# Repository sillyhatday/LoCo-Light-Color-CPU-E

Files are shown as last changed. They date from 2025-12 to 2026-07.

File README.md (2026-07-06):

# Introduction

As you may know, there are different revision CPUs that came in the GBC. All are compatible with each other except the last revision. This project allows for the use of that version inside of a Gameboy Light form factor.

The final revision CGB was cost cut as much as possible, Nintendo removed as much as they could from the console. All filtering removed by Nintendo has been removed from this also.

There is a bit of shell trimming required when assembling. The front face of the shell requires trimming for the screen like all IPS screen replacements. There is some trimming needed around the click wheel also as it's bigger than the orginal contrast wheel on a Light console. I'll document this when I have completed the build.

>[!IMPORTANT]
>This version only works with CGB-CPU-06 revisions, known as CPU-E

>[!NOTE]
>Limited new parts are needed, the 2.5v regulator and toggle wheel. I could have used the regulator from the donor, it just has an odd pin out. Such a small part is easy to loose or damage, so I went with a new part with a standard pin out. Everything else is the same as the original version.

Here is Natalie's origiinal readme with my images.

# LoCo (Light Color) - NatalieTheNerd

LoCo-CPU-E-Front

LoCo-CPU-E-Femboys







LoCo = Light Color. This project allows you to put a Game Boy Color in a Game Boy Light shell. Full Light colour PCB using the original parts. This board is made with modern screen kits in mind meaning it does not have the voltage rails for the original screen.

**ORDER AT 1MM WITH ENIG**

You can support me on Ko-Fi or by buying the board directly from me [my store](https://nataliethenerd.com/collections/all)

I also occasionally sell pre built PCBs on my store.



## Building

LoCo-PCB-Front-Back

> [!WARNING]
> I am not responsible for your skill issues!

>[!TIP]
>Some details that will need your atention during assembly are [here](SHELLTRIMMING.md)

This board uses all the parts of an original Game Boy Color minus the IR and original screen circuit. Most parts are in the same spot, however if you are having trouble you can check the [interactive BOM](https://nataliethenerd.github.io/loco.html)

The thumbwheel circuit can be connected to an OSD screen to control brightness. The two touch pad wires and be connected to the pads labelled ↑↓ on the back top left side of the board. The select, A and B pads are easy connection pads for the screen also. 

screenguide

**My recommendations** 

- New power regulator like my [Safer Charge DC](https://nataliethenerd.com/products/safer-charge-dc)
- [Q5 OSD Game Boy Color screen](https://s.click.aliexpress.com/e/_DmvDS95). The OSD allows you to move the screen

**New parts**

- [Thumbwheel](https://s.click.aliexpress.com/e/_DFcsKf1)

## Thanks
- Hozy for the pushing me to do the first ever Light Color
- Console and Casks for the thumbwheel circuit

## Follow me

If you are into Game Boy modding or retro gaming, please consider using code "NatalieTheNerd" at:

• [Retro Modding](http://RetroModding.com) 

• [Retro Game Repair Shop](http://RetroGameRepairShop.com) 

• [Extreme Rate](http://ExtremeRate.com)

**My socials**

• [Twitter](https://twitter.com/natalie_thenerd) 

• [BlueSky](https://bsky.app/profile/nataliethenerd.com) 

• [Instagram](https://www.instagram.com/natalie.thenerd/) 

• [Modded Gameboy Club](https://moddedgameboy.club/) - a club dedicated to the modification of Game Boys, freely sharing resources

## License

Please do not remove my logo, website and name.



The CC BY-SA 4.0 (Creative Commons Attribution-ShareAlike 4.0 International) license allows you to:

1. **Share** - Copy and redistribute the material in any medium or format.
2. **Adapt** - Remix, transform, and build upon the material for any purpose, even commercially.

### Conditions:

- **Attribution** - You must give appropriate credit, provide a link to the license, and indicate if changes were made. You may do so in any reasonable manner, but not in any way that suggests the licensor endorses you or your use.
- **ShareAlike** - If you remix, transform, or build upon the material, you must distribute your contributions under the same license as the original.

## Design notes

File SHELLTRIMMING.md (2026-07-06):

When it come time to assemble, there are a few points that require attention. Some of these I could fix in the PCB layout, but I cdon't see many poeple actually building this.

The contrast wheel is now replaced with the toggle wheel. This is larger than the original. The back shell requires the gap making larger.

LoCo-Contrast

The donor GBC crystal will likely be the wrong footprint. This was my temporary fix until getting a different crystal.

LoCo-CPU-Crystal

Here you can see there are some parts that will interfere with the back shell. It seem the last GBC rev comes with some fat fuses which are close to the back shell. One of the filters is also directly under the back shell, that is an issue in the original design. I could fix it, but it's an easy shell trim.

Some of these parts are removed in the newest model.

LoCo-Power-2

A clearer look without the shell. If using the Bucket Mouse voltage regulator, keep in mind where the extra wire is run. I could add a solder jumper for if the user wants to use that regulator. Maybe I will, but not right now.

LoCo-Power

Extra Optional Tips:

If using an alternative power regulator, I suggest removing the black part once the pins are all soldered. The height of the regulator from the main PCB pushes it into the front shell. I have not removed them and should do that.

regulatorSdeProfile

These pins collide with the front shell.

regulatorAngledView

I prefer the screen controls to be different from the assignments on the PCB. Swapping A and Select seems more intuitive to me.

buttonSolderPads

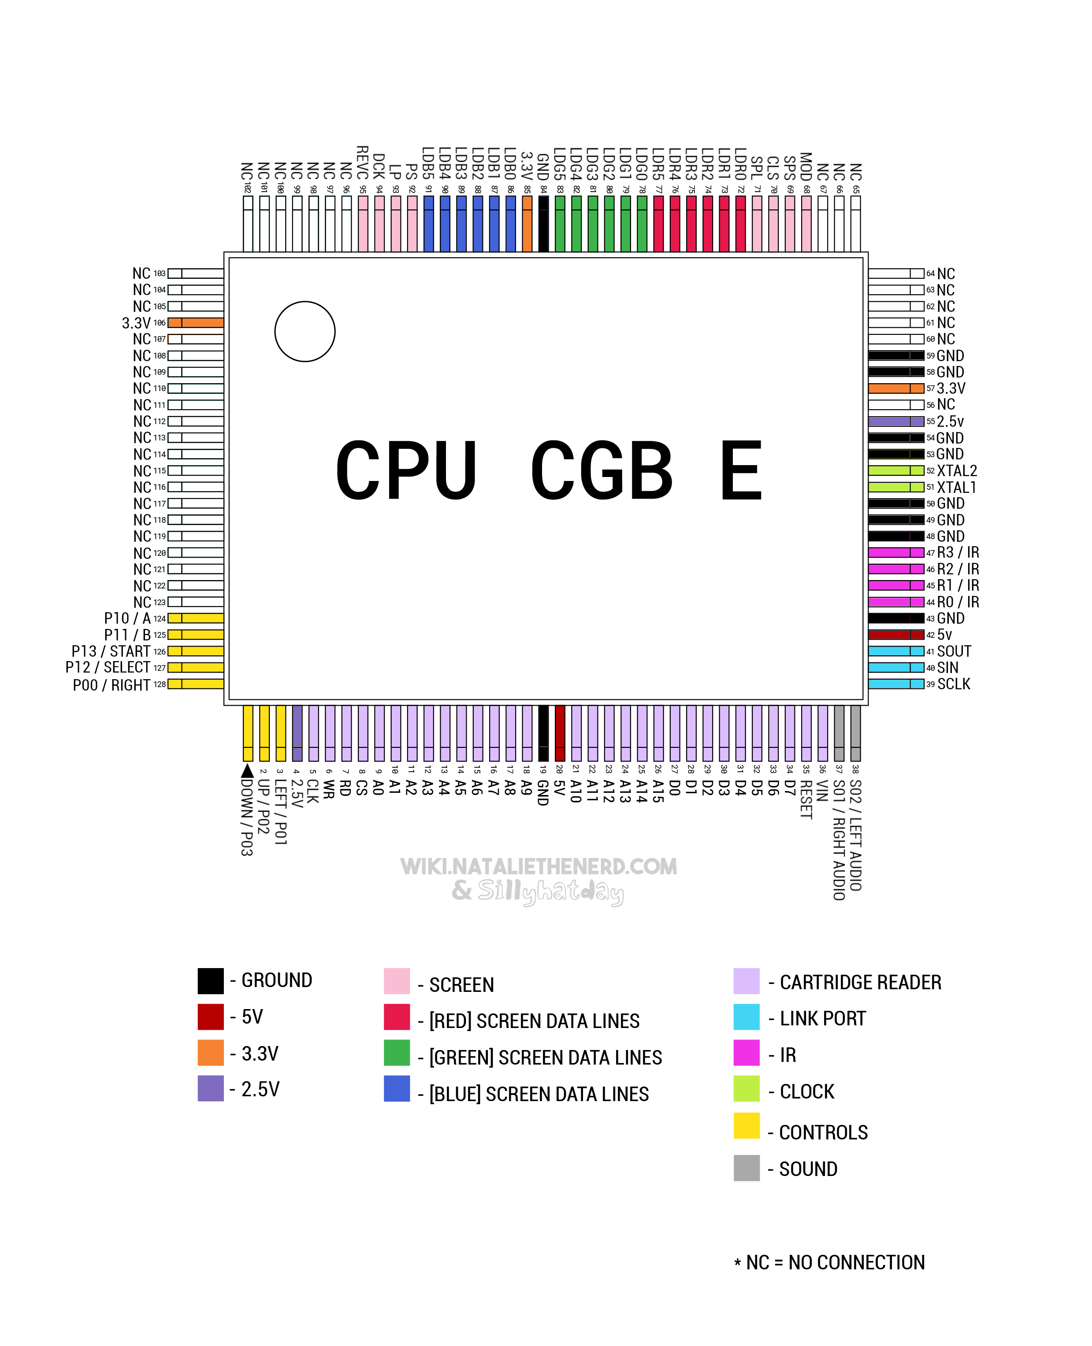
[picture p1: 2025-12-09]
GBC-CPU-E-PINOUT.png

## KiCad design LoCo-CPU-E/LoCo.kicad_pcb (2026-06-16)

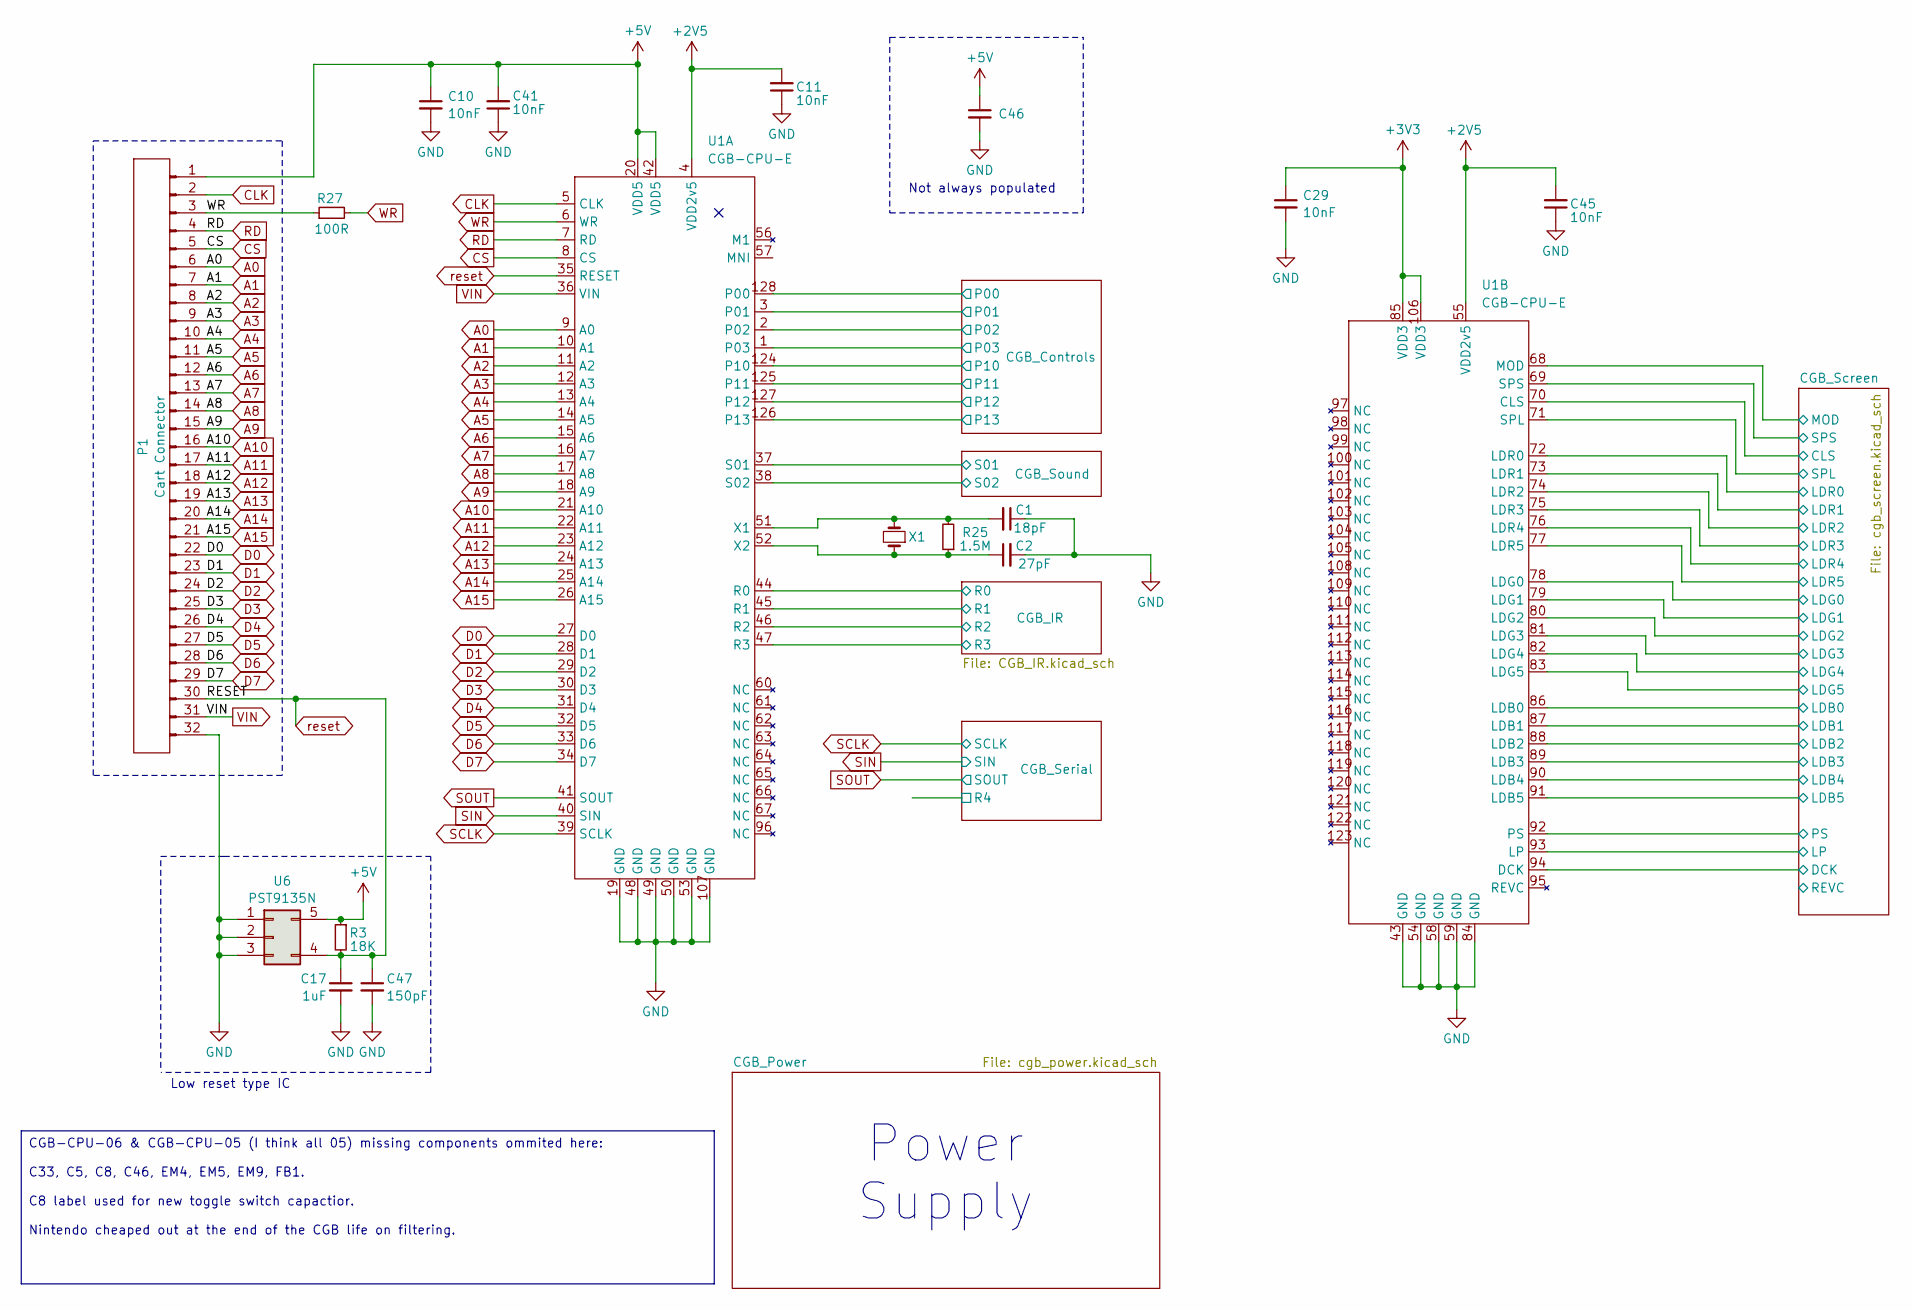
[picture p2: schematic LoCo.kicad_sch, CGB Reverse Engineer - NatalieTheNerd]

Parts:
C1: 18pF; C_0603_1608Metric
C2: 27pF; C_0603_1608Metric
C10, C11, C29, C41, C45: 10nF; C_0603_1608Metric
C17: 1uF; C_0603_1608Metric
C46: C_0603_1608Metric
C47: 150pF; C_0603_1608Metric
P1: Cart Connector; Cart CGB
R3: 18K; R_0603_1608Metric
R25: 1.5M; R_0603_1608Metric
R27: 100R; R_0603_1608Metric
U1: CGB-CPU-E; CPU CGB
U6: PST9135N; SOT-23-5
X1: Crystal_Small; Crystal CGB

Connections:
+2V5: C11.2, C45.2, U1.4 (VDD2v5), U1.55 (VDD2v5); also elsewhere on the board
+3V3: C29.1, U1.85 (VDD3), U1.106 (VDD3); also elsewhere on the board
+5V: C10.1, C41.2, C46.1, P1.1, R3.1, U1.20 (VDD5), U1.42 (VDD5), U6.5; also elsewhere on the board
/CGB_Controls/P00: U1.128 (P00); also elsewhere on the board
/CGB_Controls/P01: U1.3 (P01); also elsewhere on the board
/CGB_Controls/P02: U1.2; also elsewhere on the board
/CGB_Controls/P03: U1.1 (P03); also elsewhere on the board
/CGB_Controls/P10: U1.124 (P10); also elsewhere on the board
/CGB_Controls/P11: U1.125 (P11); also elsewhere on the board
/CGB_Controls/P12: U1.127 (P12); also elsewhere on the board
/CGB_Controls/P13: U1.126 (P13); also elsewhere on the board
/CGB_Screen/CLS: U1.70 (CLS); also elsewhere on the board
/CGB_Screen/DCK: U1.94 (DCK); also elsewhere on the board
/CGB_Screen/LDB0: U1.86 (LDB0); also elsewhere on the board
/CGB_Screen/LDB1: U1.87 (LDB1); also elsewhere on the board
/CGB_Screen/LDB2: U1.88 (LDB2); also elsewhere on the board
/CGB_Screen/LDB3: U1.89 (LDB3); also elsewhere on the board
/CGB_Screen/LDB4: U1.90 (LDB4); also elsewhere on the board
/CGB_Screen/LDB5: U1.91 (LDB5); also elsewhere on the board
/CGB_Screen/LDG0: U1.78 (LDG0); also elsewhere on the board
/CGB_Screen/LDG1: U1.79 (LDG1); also elsewhere on the board
/CGB_Screen/LDG2: U1.80 (LDG2); also elsewhere on the board
/CGB_Screen/LDG3: U1.81 (LDG3); also elsewhere on the board
/CGB_Screen/LDG4: U1.82 (LDG4); also elsewhere on the board
/CGB_Screen/LDG5: U1.83 (LDG5); also elsewhere on the board
/CGB_Screen/LDR0: U1.72 (LDR0); also elsewhere on the board
/CGB_Screen/LDR1: U1.73 (LDR1); also elsewhere on the board
/CGB_Screen/LDR2: U1.74 (LDR2); also elsewhere on the board
/CGB_Screen/LDR3: U1.75 (LDR3); also elsewhere on the board
/CGB_Screen/LDR4: U1.76 (LDR4); also elsewhere on the board
/CGB_Screen/LDR5: U1.77 (LDR5); also elsewhere on the board
/CGB_Screen/LP: U1.93 (LP); also elsewhere on the board
/CGB_Screen/MOD: U1.68 (MOD); also elsewhere on the board
/CGB_Screen/PS: U1.92 (PS); also elsewhere on the board
/CGB_Screen/SPL: U1.71 (SPL); also elsewhere on the board
/CGB_Screen/SPS: U1.69 (SPS); also elsewhere on the board
/CGB_Sound/S01: U1.37 (S01); also elsewhere on the board
/CGB_Sound/S02: U1.38 (S02); also elsewhere on the board
/R0: U1.44 (R0)
/R1: U1.45 (R1)
/R2: U1.46 (R2)
/R3: U1.47 (R3)
A0: P1.6, U1.9 (A0)
A1: P1.7, U1.10 (A1)
A2: P1.8, U1.11 (A2)
A3: P1.9, U1.12 (A3)
A4: P1.10, U1.13 (A4)
A5: P1.11, U1.14 (A5)
A6: P1.12, U1.15 (A6)
A7: P1.13, U1.16 (A7)
A8: P1.14, U1.17 (A8)
A9: P1.15, U1.18 (A9)
A10: P1.16, U1.21 (A10)
A11: P1.17, U1.22 (A11)
A12: P1.18, U1.23 (A12)
A13: P1.19, U1.24 (A13)
A14: P1.20, U1.25 (A14)
A15: P1.21, U1.26 (A15)
CLK: P1.2, U1.5 (CLK)
CS: P1.5, U1.8 (CS)
D0: P1.22, U1.27 (D0)
D1: P1.23, U1.28 (D1)
D2: P1.24, U1.29 (D2)
D3: P1.25, U1.30 (D3)
D4: P1.26, U1.31 (D4)
D5: P1.27, U1.32 (D5)
D6: P1.28, U1.33 (D6)
D7: P1.29, U1.34 (D7)
GND: C1.1, C2.2, C10.2, C11.1, C17.2, C29.2, C41.1, C45.1, C46.2, C47.2, P1.32, U1.19 (GND), U1.43 (GND), U1.48 (GND), U1.49 (GND), U1.50 (GND), U1.53 (GND), U1.54 (GND), U1.58 (GND), U1.59 (GND), U1.84 (GND), U1.107 (GND), U6.1, U6.2, U6.3; also elsewhere on the board
unnamed: C1.2, R25.2, U1.51 (X1), X1.2
unnamed: C2.1, R25.1, U1.52 (X2), X1.1
RD: P1.4, U1.7 (RD)
SCLK: U1.39 (SCLK); also elsewhere on the board
SIN: U1.40 (SIN); also elsewhere on the board
SOUT: U1.41 (SOUT); also elsewhere on the board
VIN: P1.31, U1.36 (VIN)
WR: P1.3, R27.1, R27.2, U1.6 (WR)
reset: C17.1, C47.1, P1.30, R3.2, U1.35 (RESET), U6.4; also elsewhere on the board

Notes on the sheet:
Not always populated
Power Supply
Low reset type IC
CGB-CPU-06 & CGB-CPU-05 (I think all 05) missing components ommited here: C33, C5, C8, C46, EM4, EM5, EM9, FB1. C8 label used for new toggle switch capactior. Nintendo cheaped out at the end of the CGB life on filtering.

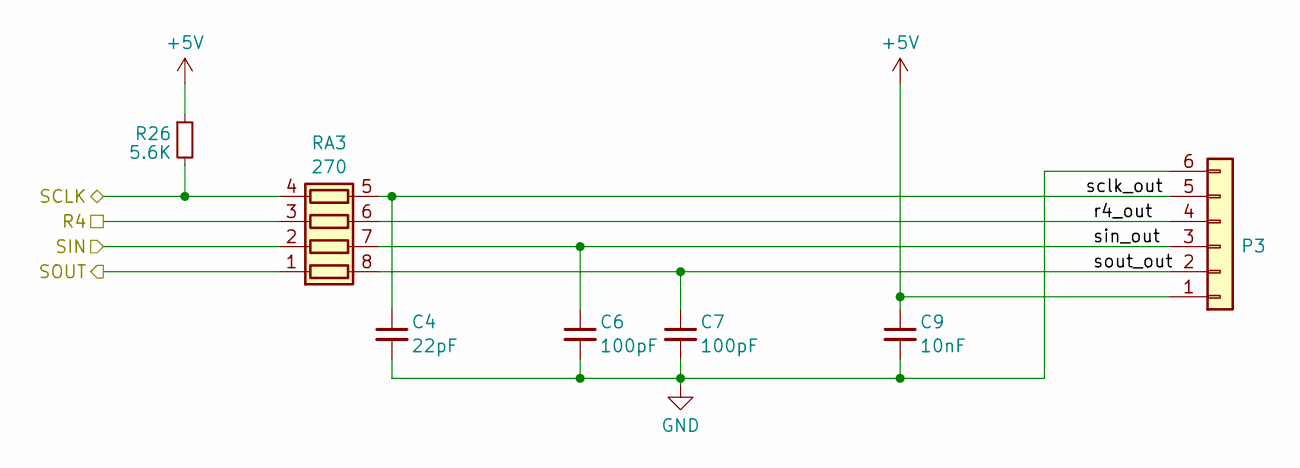
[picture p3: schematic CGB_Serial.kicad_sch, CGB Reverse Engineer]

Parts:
C4: 22pF; C_0603_1608Metric
C6, C7: 100pF; C_0603_1608Metric
C9: 10nF; C_0603_1608Metric
P3: Conn_01x06; Serial CGB
R26: 5.6K; R_0603_1608Metric
RA3: 270; R_Array_Concave_4x0603

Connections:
+5V: C9.1, P3.1, R26.1; also elsewhere on the board
/CGB_Serial/R4: RA3.3 (R3.1)
/CGB_Serial/r4_out: P3.4, RA3.6 (R3.2)
/CGB_Serial/sclk_out: C4.1, P3.5, RA3.5 (R4.2)
/CGB_Serial/sin_out: C6.1, P3.3, RA3.7 (R2.2)
/CGB_Serial/sout_out: C7.1, P3.2, RA3.8 (R1.2)
GND: C4.2, C6.2, C7.2, C9.2, P3.6; also elsewhere on the board
SCLK: R26.2, RA3.4 (R4.1); also elsewhere on the board
SIN: RA3.2 (R2.1); also elsewhere on the board
SOUT: RA3.1 (R1.1); also elsewhere on the board

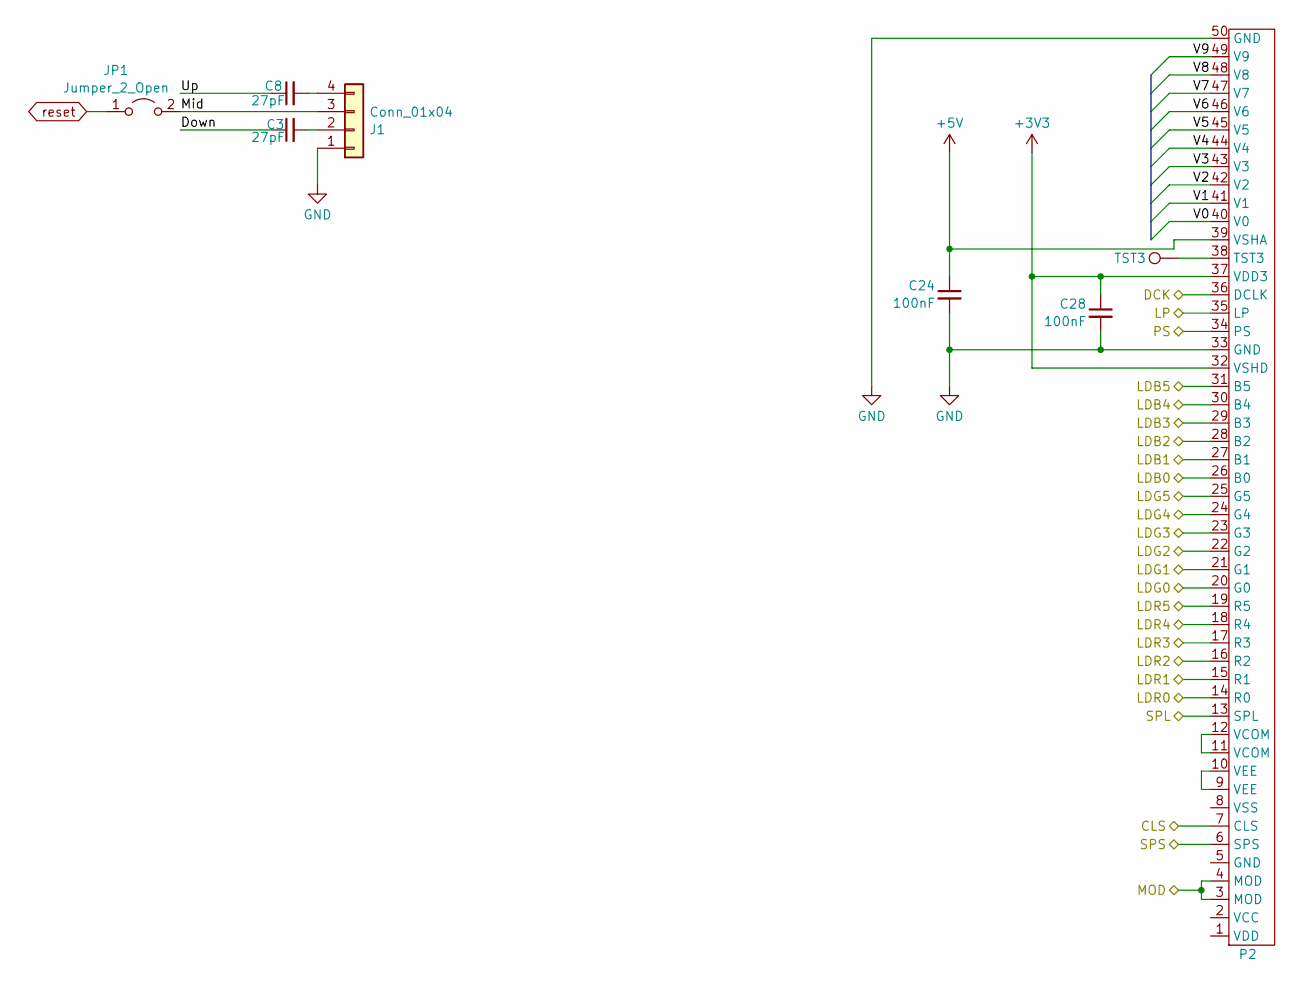
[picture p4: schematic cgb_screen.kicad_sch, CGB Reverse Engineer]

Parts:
C3, C8: 27pF; R_0603_1608Metric
C24, C28: 100nF; C_0603_1608Metric
J1: Conn_01x04; Thumbwheel toggle switch
JP1: Jumper_2_Open; SolderJumper-2_P1.3mm_Open_RoundedPad1.0x1.5mm
P2: Screen CGB
TST3: TestPoint

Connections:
+3V3: C28.1, P2.32 (VSHD), P2.37 (VDD3); also elsewhere on the board
+5V: C24.1, P2.39 (VSHA); also elsewhere on the board
/CGB_Screen/CLS: P2.7 (CLS); also elsewhere on the board
/CGB_Screen/DCK: P2.36 (DCLK); also elsewhere on the board
/CGB_Screen/Down: C3.1
/CGB_Screen/LDB0: P2.26 (B0); also elsewhere on the board
/CGB_Screen/LDB1: P2.27 (B1); also elsewhere on the board
/CGB_Screen/LDB2: P2.28 (B2); also elsewhere on the board
/CGB_Screen/LDB3: P2.29 (B3); also elsewhere on the board
/CGB_Screen/LDB4: P2.30 (B4); also elsewhere on the board
/CGB_Screen/LDB5: P2.31 (B5); also elsewhere on the board
/CGB_Screen/LDG0: P2.20 (G0); also elsewhere on the board
/CGB_Screen/LDG1: P2.21 (G1); also elsewhere on the board
/CGB_Screen/LDG2: P2.22 (G2); also elsewhere on the board
/CGB_Screen/LDG3: P2.23 (G3); also elsewhere on the board
/CGB_Screen/LDG4: P2.24 (G4); also elsewhere on the board
/CGB_Screen/LDG5: P2.25 (G5); also elsewhere on the board
/CGB_Screen/LDR0: P2.14 (R0); also elsewhere on the board
/CGB_Screen/LDR1: P2.15 (R1); also elsewhere on the board
/CGB_Screen/LDR2: P2.16 (R2); also elsewhere on the board
/CGB_Screen/LDR3: P2.17 (R3); also elsewhere on the board
/CGB_Screen/LDR4: P2.18 (R4); also elsewhere on the board
/CGB_Screen/LDR5: P2.19 (R5); also elsewhere on the board
/CGB_Screen/LP: P2.35 (LP); also elsewhere on the board
/CGB_Screen/MOD: P2.3 (MOD), P2.4 (MOD); also elsewhere on the board
/CGB_Screen/Mid: J1.3, JP1.2 (B)
/CGB_Screen/PS: P2.34 (PS); also elsewhere on the board
/CGB_Screen/SPL: P2.13 (SPL); also elsewhere on the board
/CGB_Screen/SPS: P2.6 (SPS); also elsewhere on the board
/CGB_Screen/Up: C8.1
/CGB_Screen/V0: P2.40 (V0)
/CGB_Screen/V1: P2.41 (V1)
/CGB_Screen/V2: P2.42 (V2)
/CGB_Screen/V3: P2.43 (V3)
/CGB_Screen/V4: P2.44 (V4)
/CGB_Screen/V5: P2.45 (V5)
/CGB_Screen/V6: P2.46 (V6)
/CGB_Screen/V7: P2.47 (V7)
/CGB_Screen/V8: P2.48 (V8)
/CGB_Screen/V9: P2.49 (V9)
GND: C24.2, C28.2, J1.1, P2.33 (GND), P2.50 (GND); also elsewhere on the board
unnamed: C3.2, J1.2
unnamed: C8.2, J1.4
unnamed: P2.38 (TST3), TST3.1
unnamed: P2.11 (VCOM), P2.12 (VCOM)
unnamed: P2.9 (VEE), P2.10 (VEE)
reset: JP1.1 (A); also elsewhere on the board

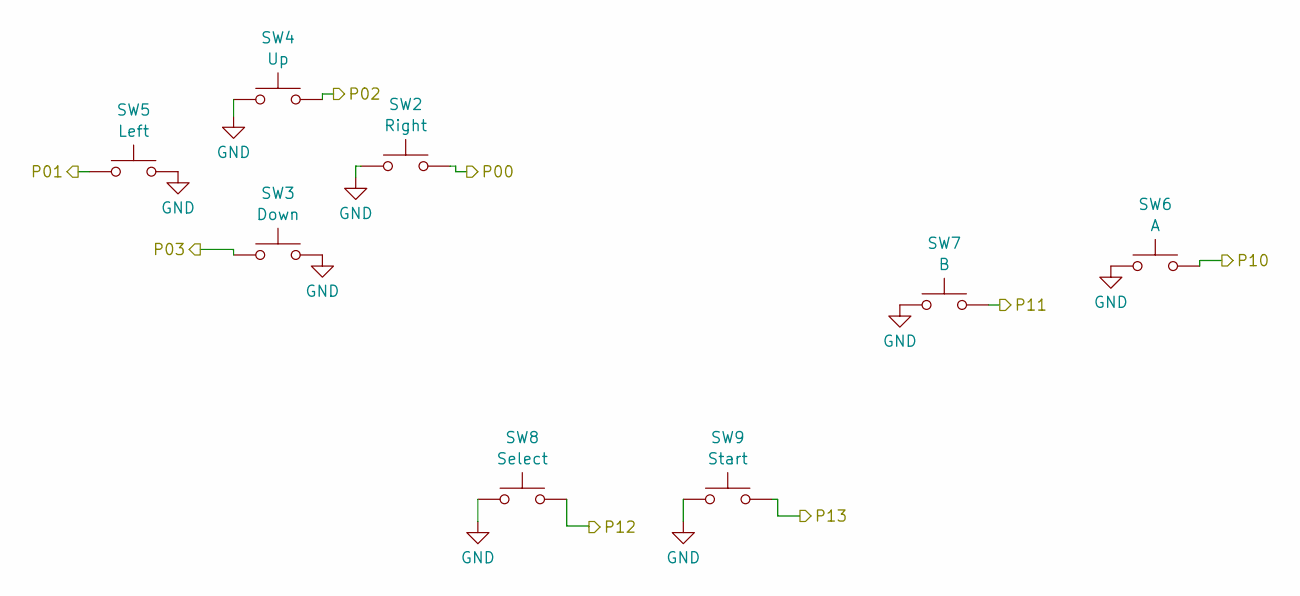
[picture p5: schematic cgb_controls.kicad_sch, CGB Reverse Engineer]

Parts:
SW2: Right; Dpad CGB
SW3: Down; Dpad CGB
SW4: Up; Dpad CGB
SW5: Left; Dpad CGB
SW6: A; AB CGB
SW7: B; AB CGB
SW8: Select; Select CGB
SW9: Start; Start CGB

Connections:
/CGB_Controls/P00: SW2.2; also elsewhere on the board
/CGB_Controls/P01: SW5.1; also elsewhere on the board
/CGB_Controls/P02: SW4.2; also elsewhere on the board
/CGB_Controls/P03: SW3.1; also elsewhere on the board
/CGB_Controls/P10: SW6.2; also elsewhere on the board
/CGB_Controls/P11: SW7.2; also elsewhere on the board
/CGB_Controls/P12: SW8.2; also elsewhere on the board
/CGB_Controls/P13: SW9.2; also elsewhere on the board
GND: SW2.1, SW3.2, SW4.1, SW5.2, SW6.1, SW7.1, SW8.1, SW9.1; also elsewhere on the board

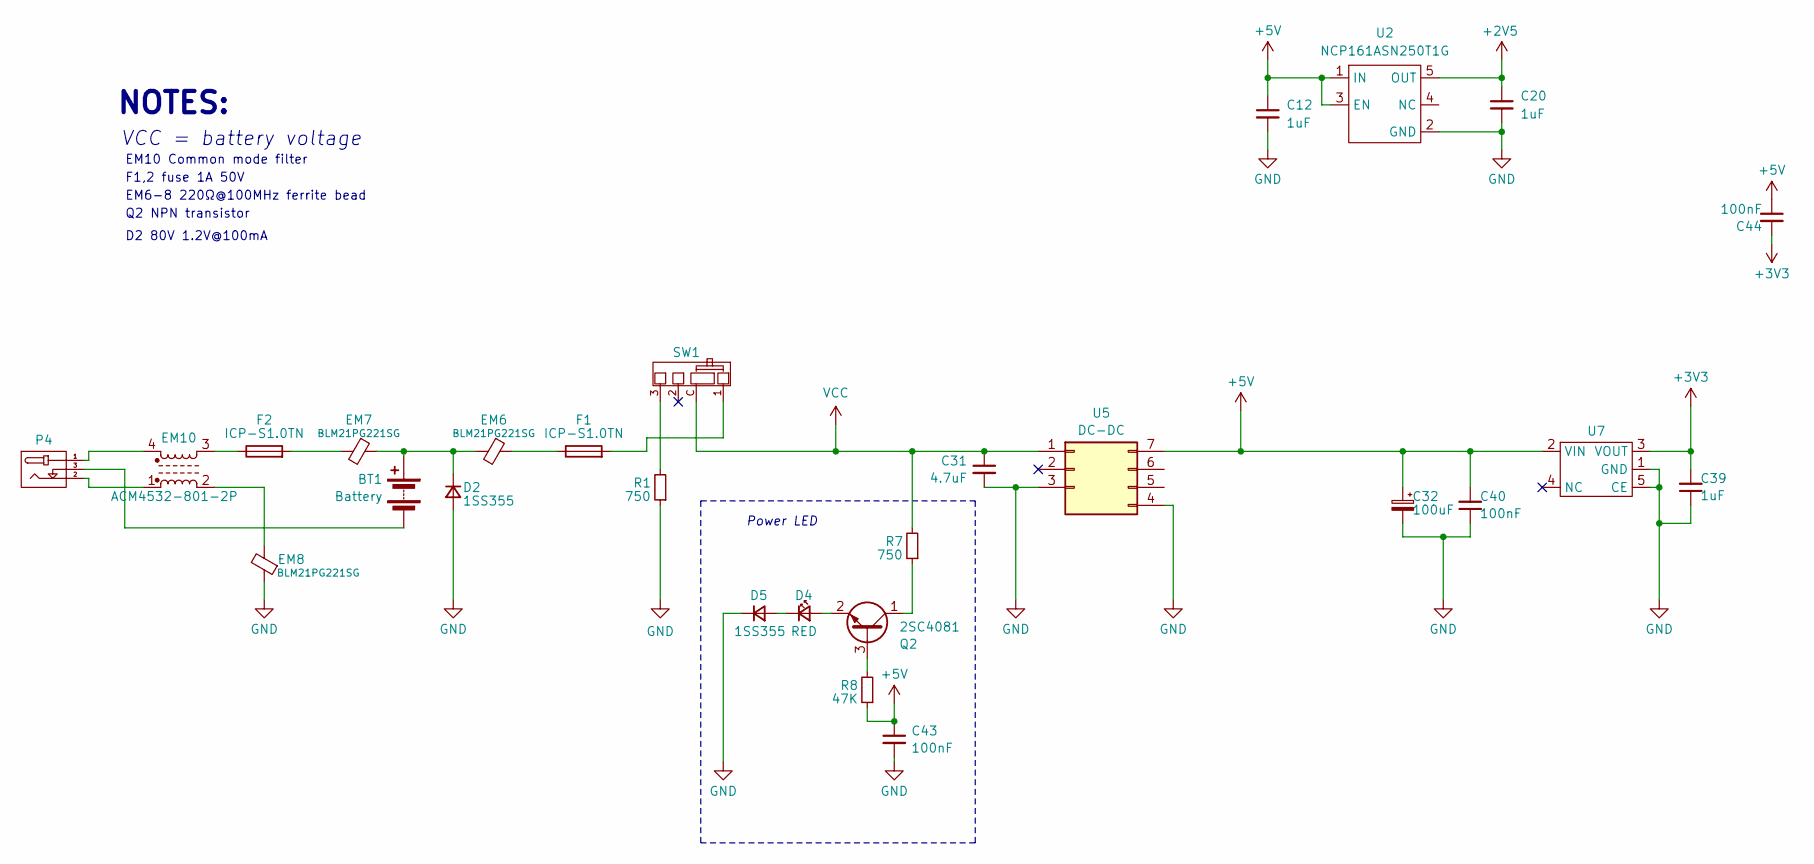
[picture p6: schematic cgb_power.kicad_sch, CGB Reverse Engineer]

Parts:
BT1: Battery; Battery CGB
C12, C20, C39: 1uF; C_0603_1608Metric
C31: 4.7uF; C_0603_1608Metric
C32: 100uF; CP_Elec_6.3x5.4
C40, C43, C44: 100nF; C_0603_1608Metric
D2, D5: 1SS355; D_SOD-323_HandSoldering
D4: RED; LED_D3.0mm
EM6, EM7, EM8: BLM21PG221SG; R_0805_2012Metric
EM10: ACM4532-801-2P; Crystal_SMD_EuroQuartz_MJ-4Pin_5.0x3.2mm
F1, F2: ICP-S1.0TN; Fuse_1206_3216Metric_Pad1.42x1.75mm_HandSolder
P4: DCJACK
Q2: 2SC4081; SOT-323_SC-70
R1, R7: 750; R_0603_1608Metric
R8: 47K; R_0603_1608Metric
SW1: Switch CGB
U2: NCP161ASN250T1G; SOT-23-5
U5: DC-DC; DC
U7: SOT-23-5

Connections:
+2V5: C20.1, U2.5 (OUT); also elsewhere on the board
+3V3: C39.2, C44.2, U7.3 (VOUT); also elsewhere on the board
+5V: C12.1, C32.1, C40.2, C43.1, C44.1, R8.1, U2.1 (IN), U2.3 (EN), U5.7, U7.2 (VIN); also elsewhere on the board
GND: C12.2, C20.2, C31.2, C32.2, C39.1, C40.1, C43.2, D2.2 (A), D5.1 (K), EM8.1, R1.1, U2.2 (GND), U5.3, U5.4, U7.1 (GND), U7.5 (CE); also elsewhere on the board
unnamed: BT1.1 (+), D2.1 (K), EM6.2, EM7.1
unnamed: BT1.2 (-), P4.3
unnamed: D4.2 (A), Q2.2 (B)
unnamed: D4.1 (K), D5.2 (A)
unnamed: EM6.1, F1.1
unnamed: EM7.2, F2.2
unnamed: EM10.1, P4.2
unnamed: EM8.2, EM10.2
unnamed: EM10.3, F2.1
unnamed: EM10.4, P4.1
unnamed: F1.2, SW1.1
unnamed: Q2.3 (C), R8.2
unnamed: Q2.1 (E), R7.1
unnamed: R1.2, SW1.3
VCC: C31.1, R7.2, SW1.C, U5.1; also elsewhere on the board

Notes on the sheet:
NOTES:
D2 80V 1.2V@100mA
EM6-8 220Ω@100MHz ferrite bead
EM10 Common mode filter
F1,2 fuse 1A 50V
Power LED
Q2 NPN transistor
VCC = battery voltage

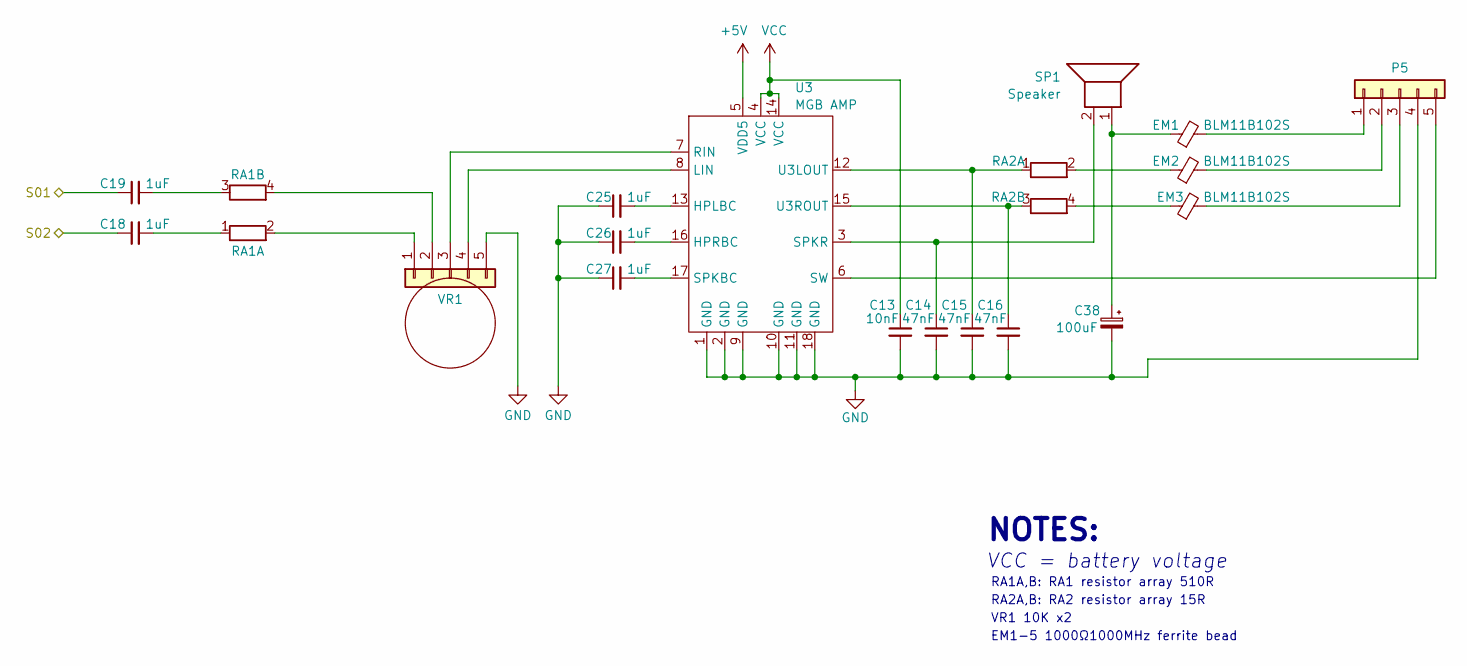
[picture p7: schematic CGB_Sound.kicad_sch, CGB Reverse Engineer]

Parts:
C13: 10nF; C_0603_1608Metric
C14, C15, C16: 47nF; C_0603_1608Metric
C18, C19, C25, C26, C27: 1uF; C_0603_1608Metric
C38: 100uF; CP_Elec_5x5.3
EM1, EM2, EM3: BLM11B102S; R_0603_1608Metric
P5: Conn_01x05; HPjack
RA1, RA2: R_Pack02_SIP_Split; R_Array_Concave_2x0603
SP1: Speaker; TestPoint_2Pads_Pitch2.54mm_Drill0.8mm
U3: MGB AMP; Amp MGB
VR1: Conn_01x05; Volume wheel CGB

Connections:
+5V: U3.5 (VDD5); also elsewhere on the board
/CGB_Sound/S01: C19.1; also elsewhere on the board
/CGB_Sound/S02: C18.1; also elsewhere on the board
GND: C13.2, C14.2, C15.2, C16.2, C25.1, C26.1, C27.1, C38.2, P5.4, U3.1 (GND), U3.2 (GND), U3.9 (GND), U3.10 (GND), U3.11 (GND), U3.18 (GND), VR1.5; also elsewhere on the board
unnamed: C38.1, EM1.1, SP1.1
unnamed: EM1.2, P5.1
unnamed: EM2.2, P5.2
unnamed: EM3.2, P5.3
unnamed: P5.5, U3.6 (SW)
unnamed: C18.2, RA1.1 (R1.1)
unnamed: RA1.2 (R1.2), VR1.1
unnamed: C19.2, RA1.3 (R2.1)
unnamed: RA1.4 (R2.2), VR1.2
unnamed: C15.1, RA2.1 (R1.1), U3.12 (U3LOUT)
unnamed: EM2.1, RA2.2 (R1.2)
unnamed: C16.1, RA2.3 (R2.1), U3.15 (U3ROUT)
unnamed: EM3.1, RA2.4 (R2.2)
unnamed: C25.2, U3.13 (HPLBC)
unnamed: C26.2, U3.16 (HPRBC)
unnamed: U3.8 (LIN), VR1.4
unnamed: U3.7 (RIN), VR1.3
unnamed: C27.2, U3.17 (SPKBC)
unnamed: C14.1, SP1.2, U3.3 (SPKR)
VCC: C13.1, U3.4 (VCC), U3.14 (VCC); also elsewhere on the board

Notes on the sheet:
EM1-5 1000Ω1000MHz ferrite bead
RA1A,B: RA1 resistor array 510R
VR1 10K x2
VCC = battery voltage
NOTES:
RA2A,B: RA2 resistor array 15R

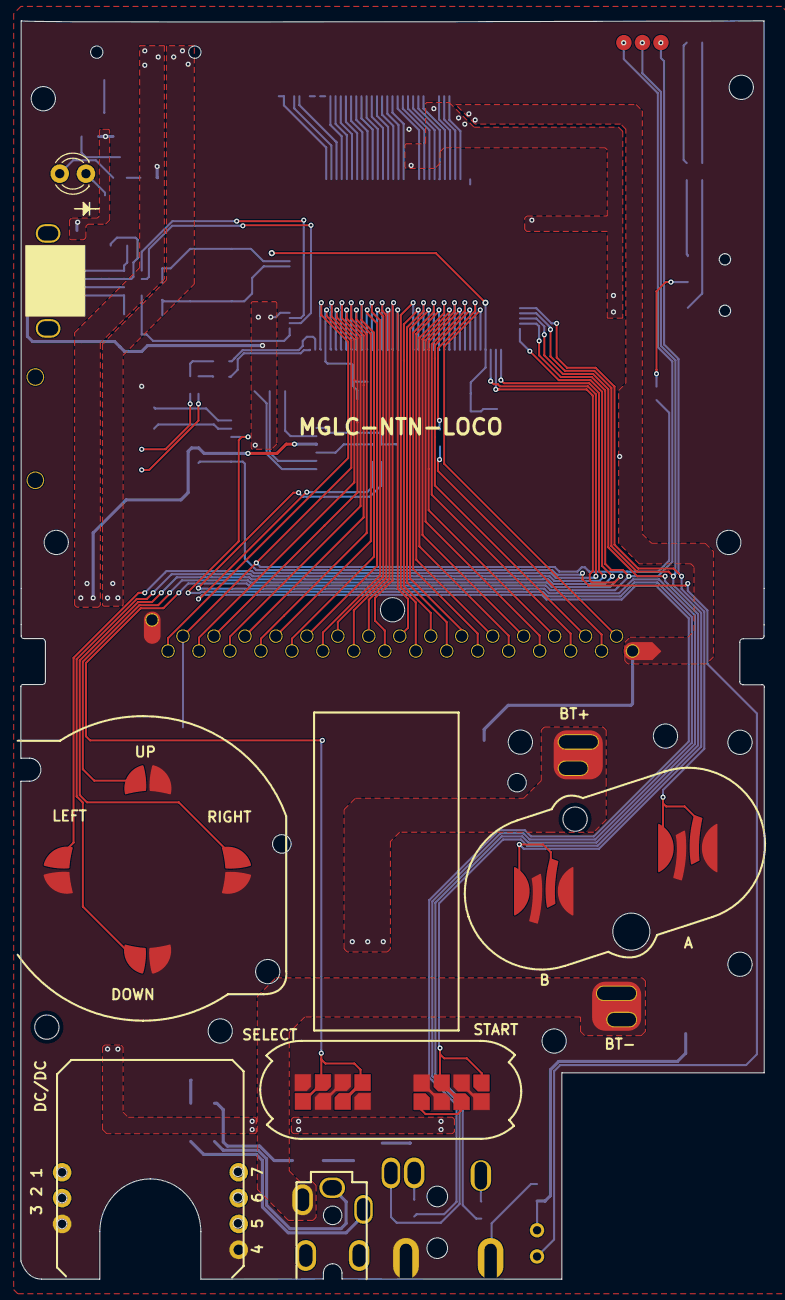
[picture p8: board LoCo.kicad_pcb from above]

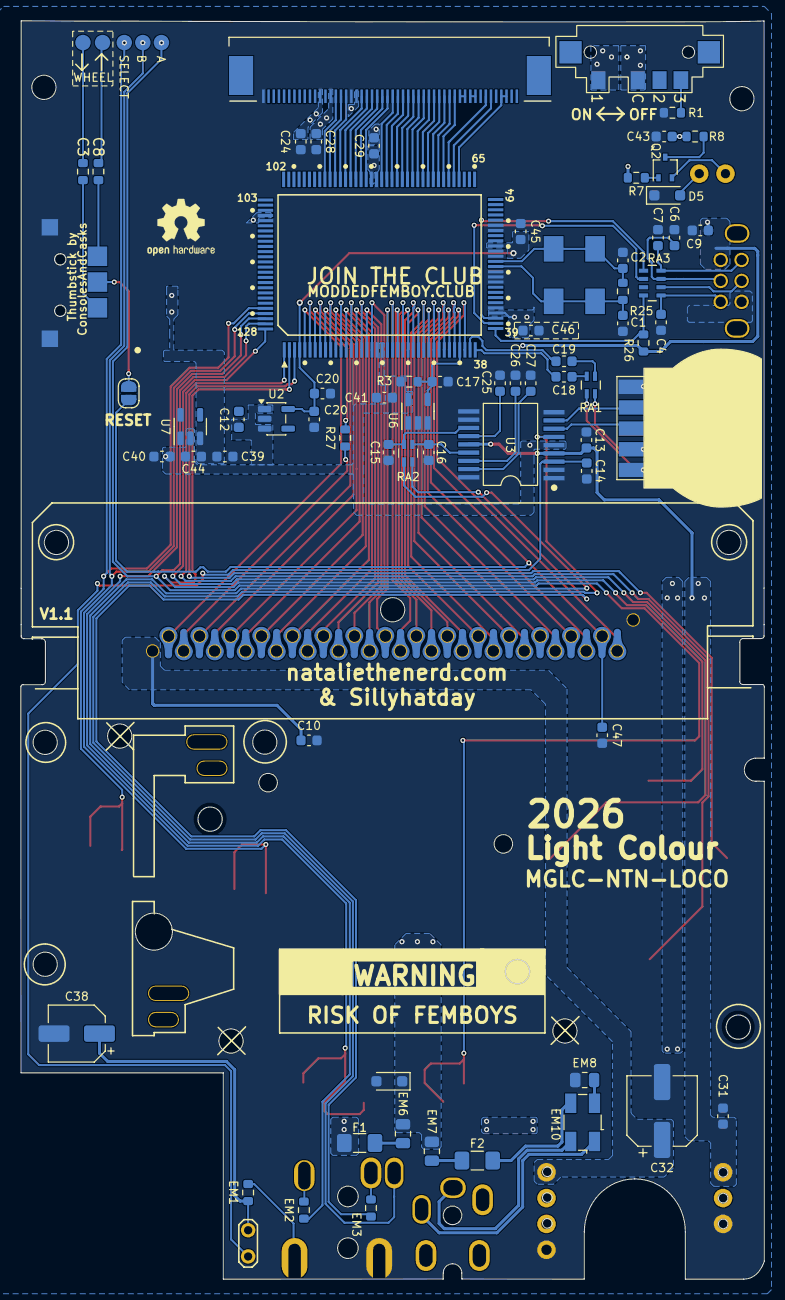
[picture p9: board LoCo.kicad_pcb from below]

Board: 2 copper layers, 72.0 x 121.9 mm, 85 parts (70 on the bottom side), 117 nets.

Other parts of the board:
C20#2: 1uF; C_0603_1608Metric

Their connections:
+2V5: C20#2.1; also elsewhere on the board
GND: C20#2.2; also elsewhere on the board

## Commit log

2025-12-08 Create KiCad-Loco-CPU-E
2025-12-08 Design files uploaded
    [CGB_IR.kicad_sch, CGB_Serial.kicad_sch, CGB_Sound.kicad_sch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]
2025-12-08 Gerbers uploaded
2026-06-16 Update README.md
    Updated readme after initial prototype build
2026-06-16 Delete KiCad-Loco-CPU-E directory
    Removed original kicad files
    [CGB_IR.kicad_sch, CGB_Serial.kicad_sch, CGB_Sound.kicad_sch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]
2026-06-16 Add files via upload
    new kicad files
    [CGB_IR.kicad_sch, CGB_Serial.kicad_sch, CGB_Sound.kicad_sch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]
2026-06-16 Add files via upload
    added gerbers
